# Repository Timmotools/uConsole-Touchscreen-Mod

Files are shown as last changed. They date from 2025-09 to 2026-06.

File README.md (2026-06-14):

# uConsole Touchscreen Modification Guide

A step-by-step guide to installing a 4.3-inch resistive touchscreen mod onto the ClockworkPI uConsole using an AIOv2 expansion board.

**UPDATE: Latest system upgrades break the original udev rules. updates are below on how to fix this using labwc**
---

## 🛠️ The Hardware

### Parts Required
* **5-inch Resistive Touch Panel:** 4-wire configuration (117 x 70mm). Available on [AliExpress](https://www.aliexpress.com/item/1005002841077197.html).
* **Resistive Touch Controller:** Available on [AliExpress](https://www.aliexpress.com/item/1005005363964306.html).
* **Bolts:** 6 x 8mm M4 button head bolts.
* **Wiring:** Wires to solder the USB touch controller to the uConsole expansion board.
* **Extension:** Ribbon cable for extending the touch panel ribbon.

### 3D Printed Parts
* `Trackball_Spacer.stl`
* `Screen_spacer.stl`

---

## 🔧 Hardware Installation

### 1. Extending the Ribbon Cable
The ribbon cable on the touch panel is too short and requires extending. Use a scrap piece of ribbon cable and solder it directly to the connector part.

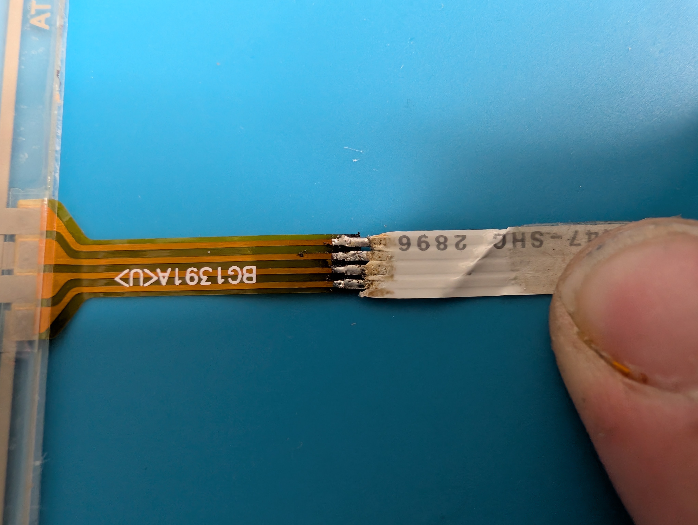
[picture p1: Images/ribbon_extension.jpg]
Ribbon Extension


Ensure you mark this ribbon cable carefully to preserve the correct polarity when connecting the controller later.

Polarity Check

Apply a piece of Kapton tape (or alternative insulating tape) over the solder joints to protect against short circuits or bending damage.

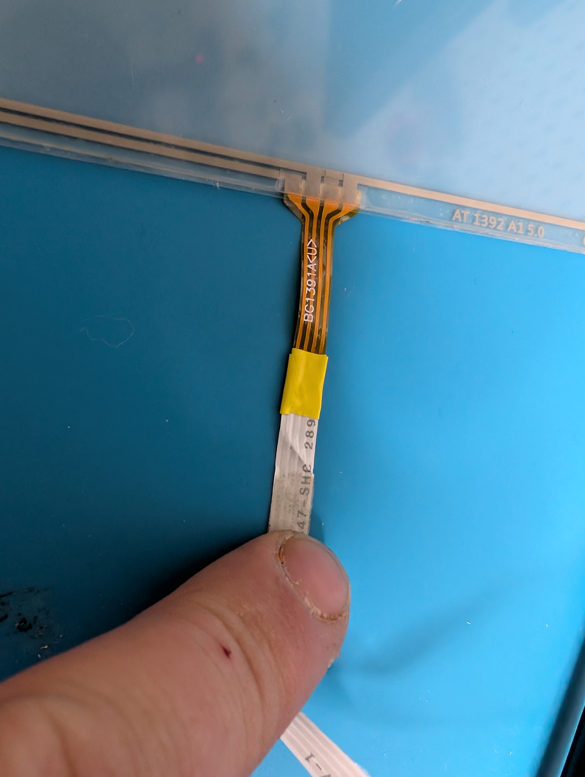
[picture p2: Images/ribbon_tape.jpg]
Ribbon Tape Protection


### 2. Feeding the Cable
This cable needs to feed in through the same housing hole as the LCD ribbon. You will need to make a sharp right-angle fold for it to fit properly.

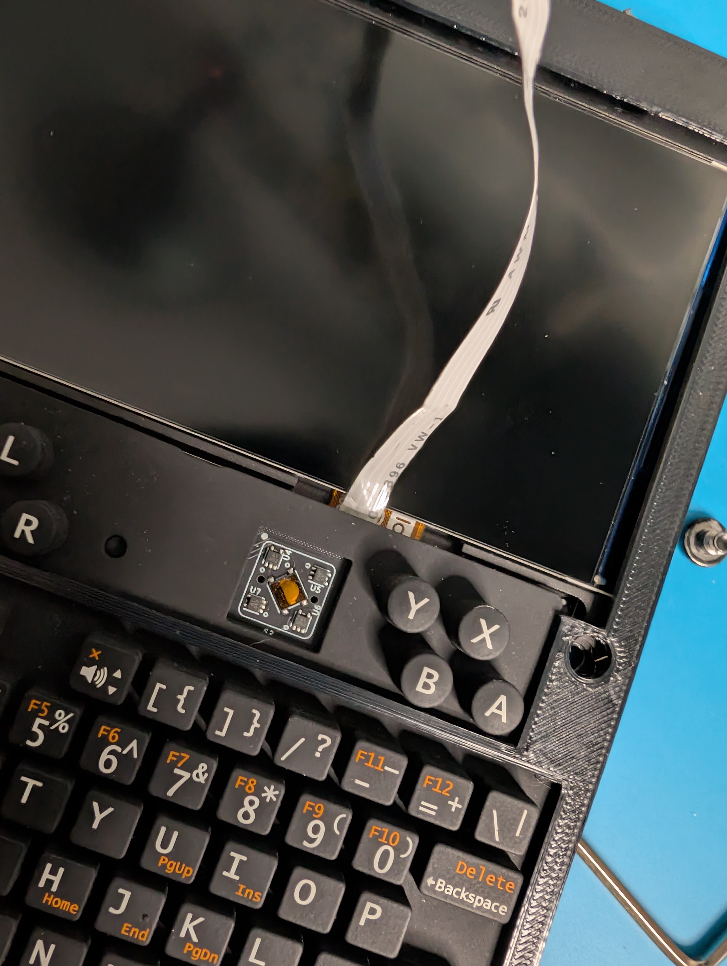
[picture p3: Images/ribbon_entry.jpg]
Ribbon Entry Location

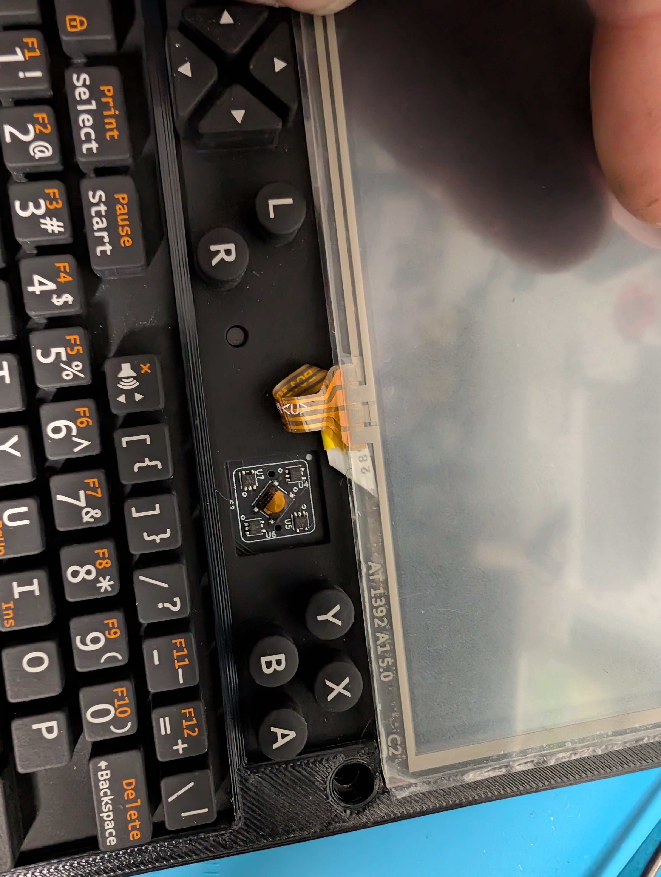
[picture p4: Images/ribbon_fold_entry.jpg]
Ribbon Fold Direction


### 3. Case Assembly
Place the 3D printed `Trackball_Spacer.stl` into the original front faceplate.

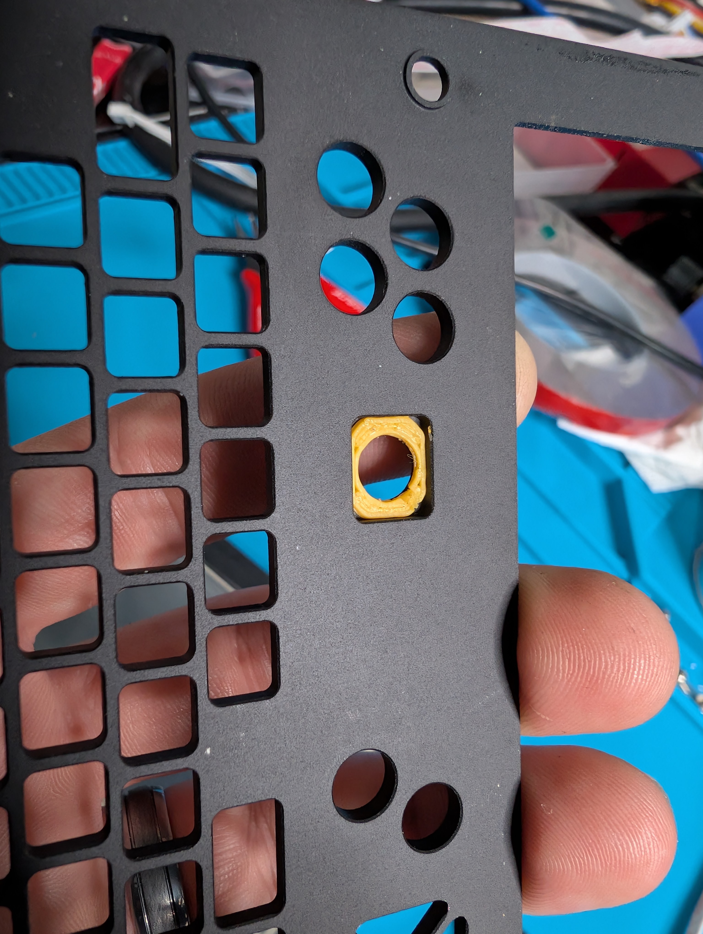
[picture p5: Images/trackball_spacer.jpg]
Trackball Spacer Installation


Install the 3D printed surround onto the main frame before placing the trackball and the front face into position. Secure the assembly using the M4 bolts. 

> 💡 *Tip: If your bolts are slightly too long, you can 3D print additional washers to take up the slack.*

---

## ⚡ Wiring and Controller Fitment

Turn over the uConsole to begin working on the internal wiring.

1. **Prep the Board:** If your controller board includes pre-installed plugs on the touch input or USB output, remove them using flush cutters or a desoldering iron.
2. **Test Fit:** Check the controller board placement. Positioning it right under the expansion board works well, but may require trimming a tiny bit off the edge of the controller card. As long as you do not cut into any active circuit tracks, the board will be fine.
   
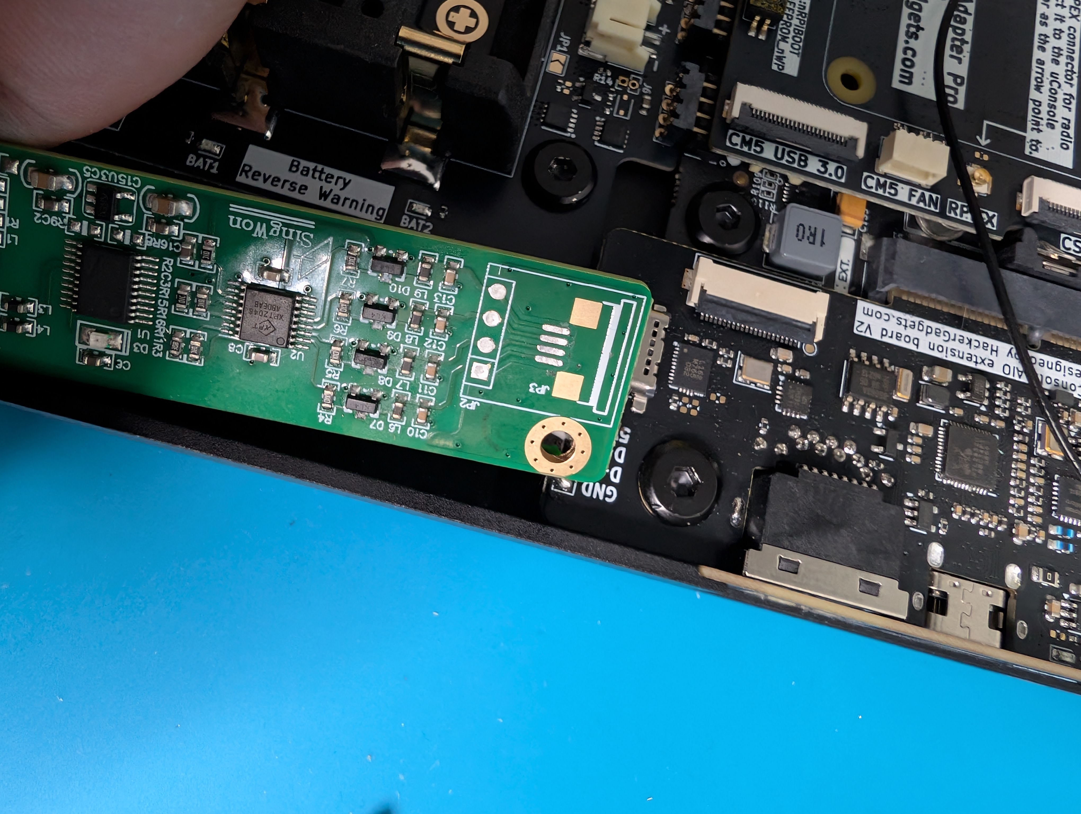
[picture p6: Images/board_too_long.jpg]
Board Modification Fitment
   

3. **Soldering:** 
   * Solder the extended touch ribbon directly to the controller board.
   * Solder the 4 USB data/power wires to the controller board.
4. **Final Tuck:** Carefully fold the ribbon cable layers so they tuck cleanly inside the case boundaries.

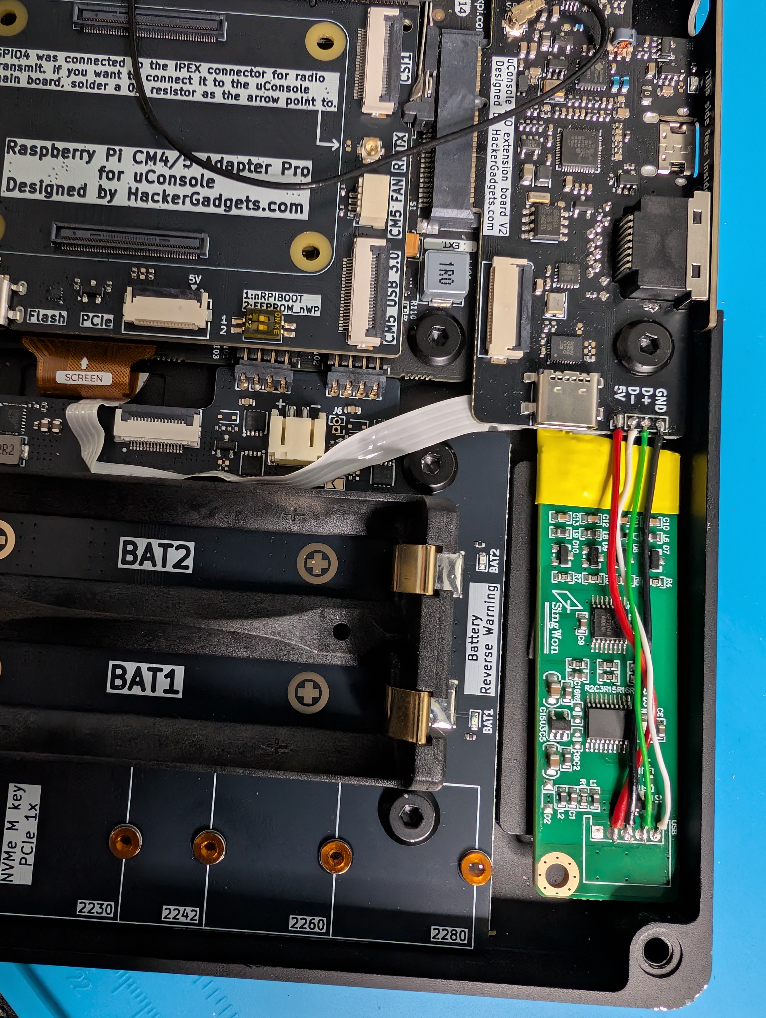
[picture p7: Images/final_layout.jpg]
Final Internal Layout


---

## 💻 Software Configuration

This configuration was validated using the recommended Debian and Ubuntu environments outlined in the [AIOv2 Setup Guide](https://hackergadgets.com).

### 1. Disable the On-Screen Keyboard
To prevent interference, disable the default OS virtual keyboard:
1. Navigate to **Pi Menu** ➔ **Preferences** ➔ **Control Centre**.
2. Under **Display Options**, change **On-screen Keyboard** to **Disabled**.

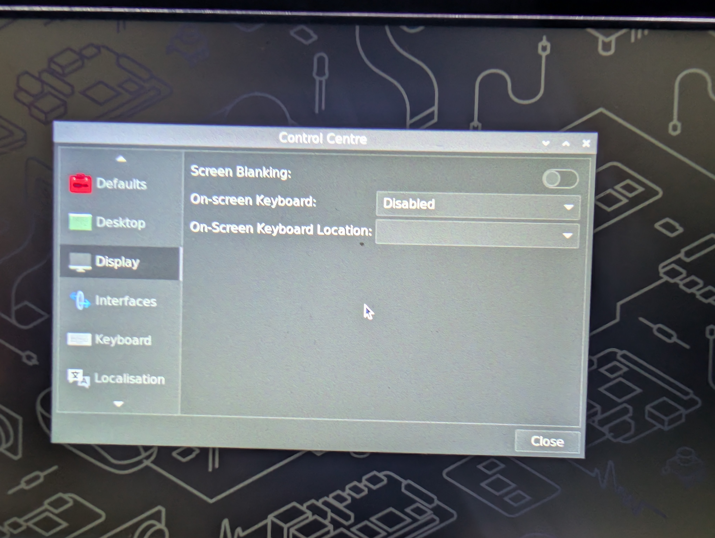
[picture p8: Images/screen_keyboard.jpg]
Disable OSK Settings


### 2. Enable USB Power via Terminal
Open your terminal application. If you are utilizing the AIOv2 board, power up the touch controller hardware rail:

```bash
# Power on the USB rail immediately
aiov2_ctl usb on

# Enable the USB rail permanently at system boot
aiov2_ctl --boot-rail usb on
```

Verify that the USB controller is recognized by the operating system:
```bash
lsusb
```

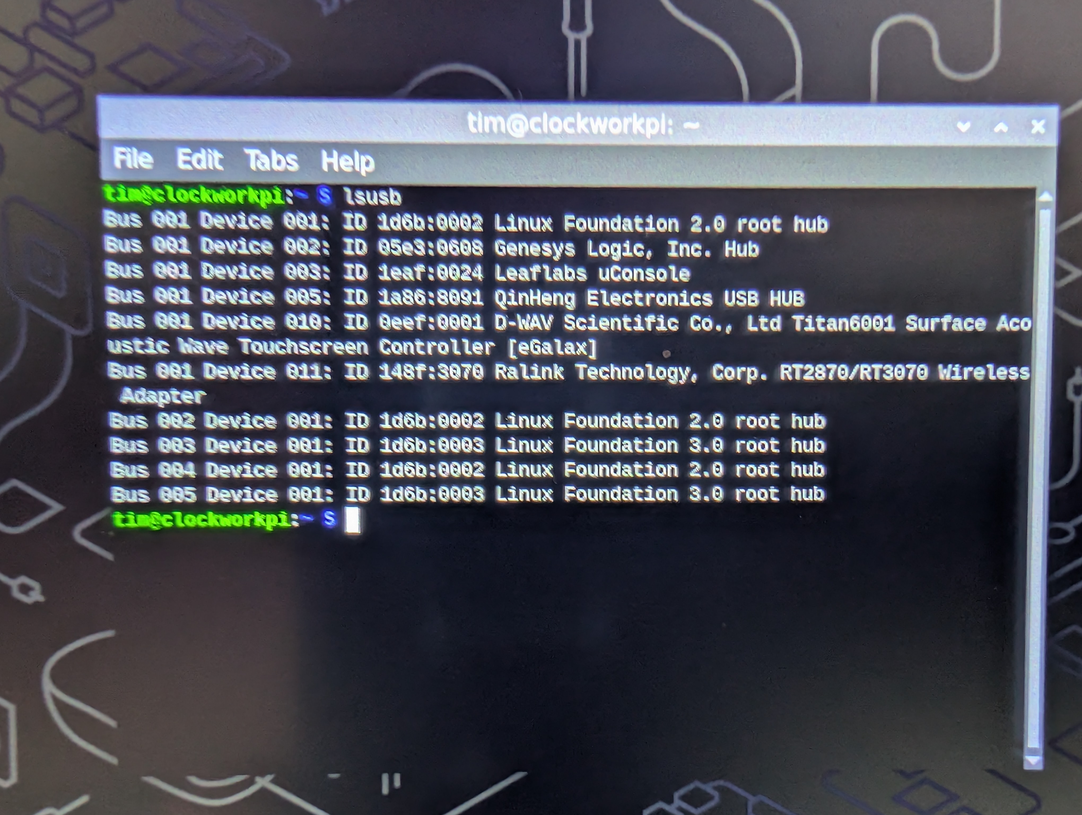
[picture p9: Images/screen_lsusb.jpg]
lsusb Output Verification


### 3. Persistent 90° Calibration Rule
Locate your touchscreen device driver string to verify its system designation:
```bash
sudo libinput list-devices
```

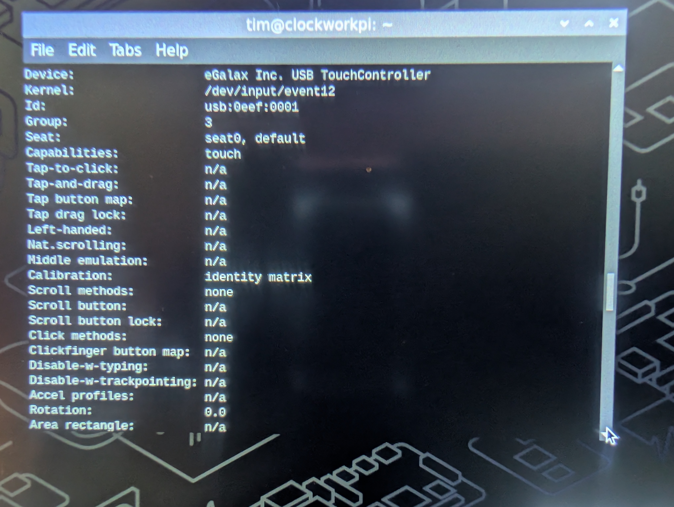
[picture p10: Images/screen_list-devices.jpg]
libinput Device Selection


Copy your hardware name (e.g., `"eGalax Inc. USB TouchController"`). Create a persistent Udev rules file to map the touch coordinates correctly for the rotated landscape panel:

```bash
sudo nano /etc/udev/rules.d/99-touchscreen-calibration.rules
```

Add the following configuration string strictly on **one single line**:

```text
ATTRS{name}=="eGalax Inc. USB TouchController", ENV{LIBINPUT_CALIBRATION_MATRIX}="0.0 1.246571 -0.085628 -1.048012 0.0 1.018752"
```

Save and exit the file (`Ctrl+X`, then `Y`, then `Enter`).

### 4. Apply Changes
Reboot your uConsole to initialize the persistent calibration matrix:
```bash
sudo reboot
```
**UPDATE:**
If the above did not work or fails to work after doing a `sudo apt update && sudo apt upgrade -y` commands then you need to update the rc.xml file instead.

```bash
sudo nano ~/.config/labwc/rc.xml
```
Look through the file and delete any lines with `touch` at the start. `Ctrl+k` deletes whole lines in nano.

At the end of the file just before `</openbox_config>` insert the following lines

```text
  <libinput>
    <device category="eGalax Inc. USB TouchController (USB 1-1.4.3)">
      <calibrationMatrix>0.0 1.246571 -0.085628 -1.048012 0.0 1.018752</calibrationMatrix>
    </device>
  </libinput>
```

Save and exit the file (`Ctrl+X`, then `Y`, then `Enter`).

Reboot your uConsole to initialize the persistent calibration matrix:
```bash
sudo reboot
```

### 5. Test and Enjoy!
Test your tracking across the panel. Note that this resistive screen configuration responds best when using a precise stylus!

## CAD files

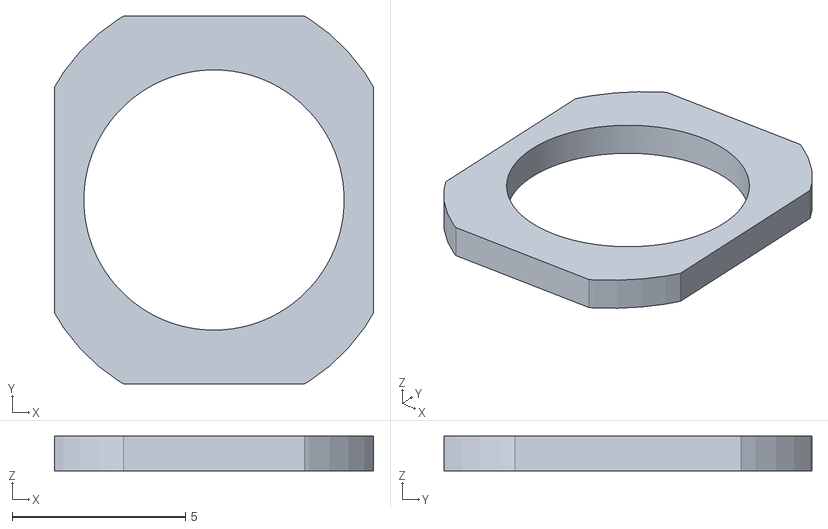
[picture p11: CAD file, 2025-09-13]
uConsole_touch_trackball_spacer.stl
9.20 x 10.6 x 1

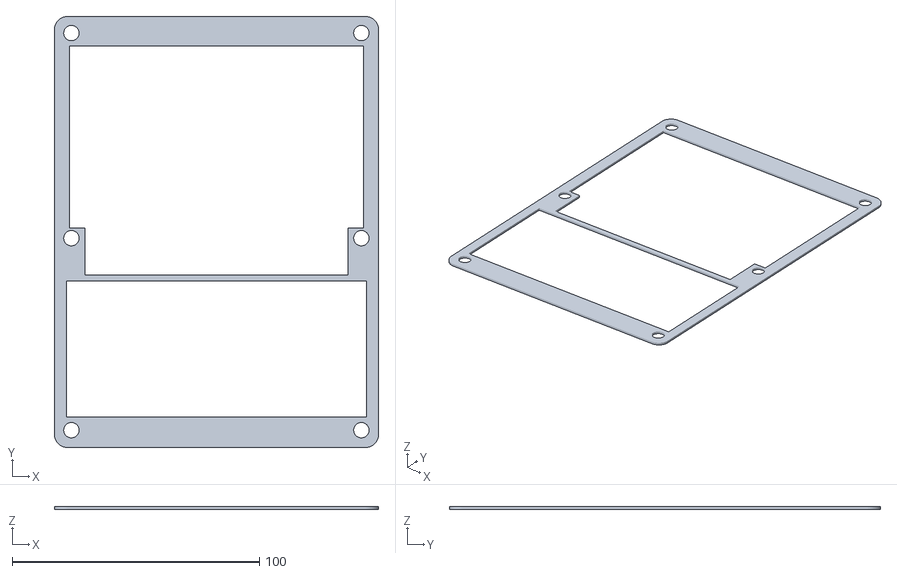
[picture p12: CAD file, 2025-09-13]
uConsole_touch_screen_spacer.stl
131.1 x 174.2 x 1.15

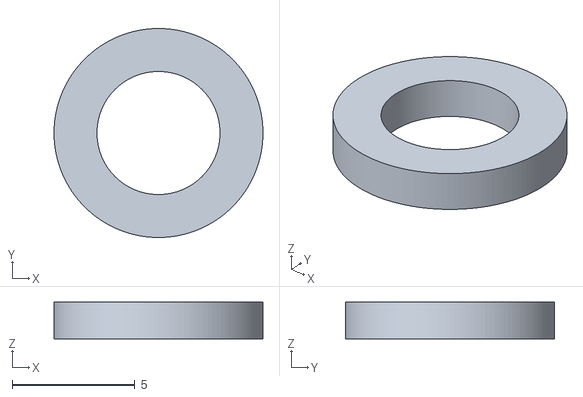
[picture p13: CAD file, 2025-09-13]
uConsole_touch_screw_washer.stl
8.50 x 8.50 x 1.50
